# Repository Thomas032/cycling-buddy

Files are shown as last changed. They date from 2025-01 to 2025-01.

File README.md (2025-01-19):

## Cycling Buddy - Smart Cycling Computer

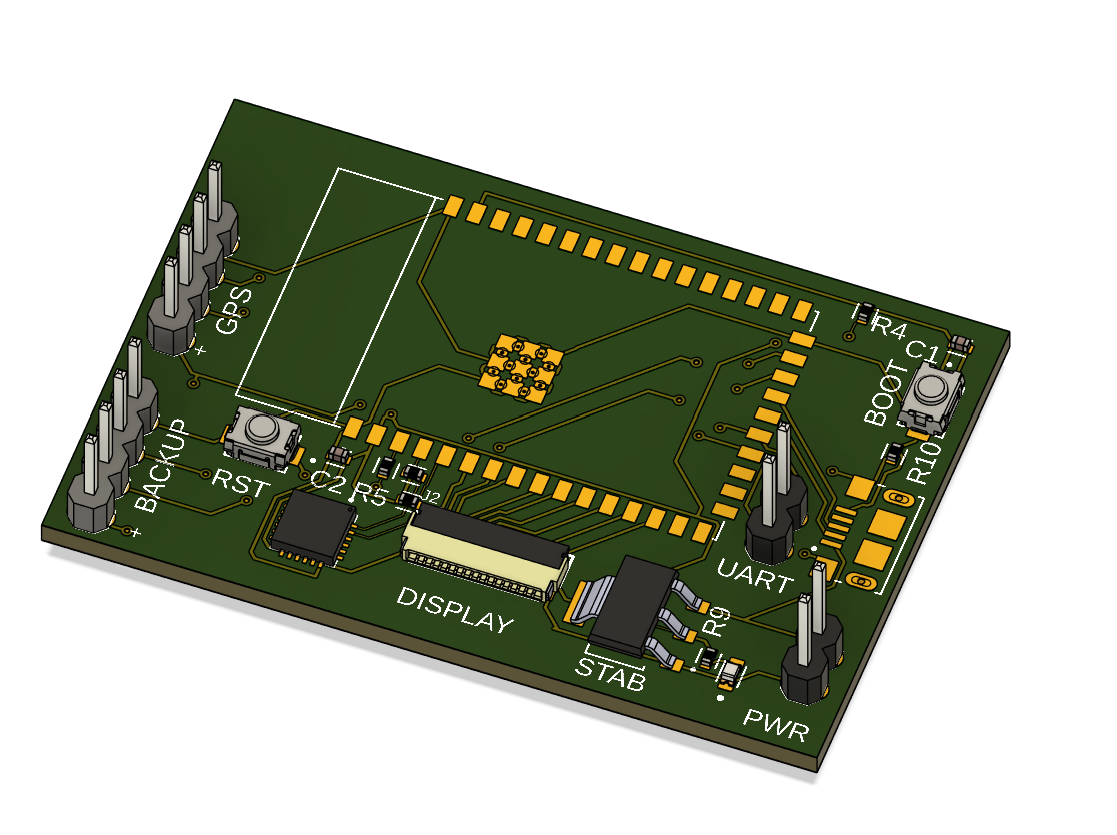
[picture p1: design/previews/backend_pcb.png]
Backend PCB
  
*The backend PCB design of Cycling Buddy.*

This is Cycling Buddy, a smart cycling computer I designed in 2023. The project aimed to fill a gap in the market while helping me improve my skills in PCB design, 3D modeling, and programming.

## Project Overview

Cycling Buddy consists of two main components:

### 1. **Compute Engine**
- **Location**: Housed within the bike’s steering shaft.
- **Features**:
  - **ESP32 Microcontroller**: The core of the compute engine, managing all system operations.
  - **Neo 6M GPS Module**: Enables real-time location tracking and navigation.
  - **MPU6050 Sensor**: Provides gyroscope and accelerometer data for precise movement and orientation tracking.
  - **Battery**: Powers the entire system.

### 2. **User Interface (UI)**
- **Features**:
  - **1.28" Round IPS Display**: Provides clear and vibrant visualization of data.
  - Buttons for user interaction and control.
- **Connection**: Wired connection to the compute engine (originally flex cable).

Due to an error in the original UI PCB design, the physical product had to be redesigned, and the UI PCB was ultimately not utilized in the final implementation.

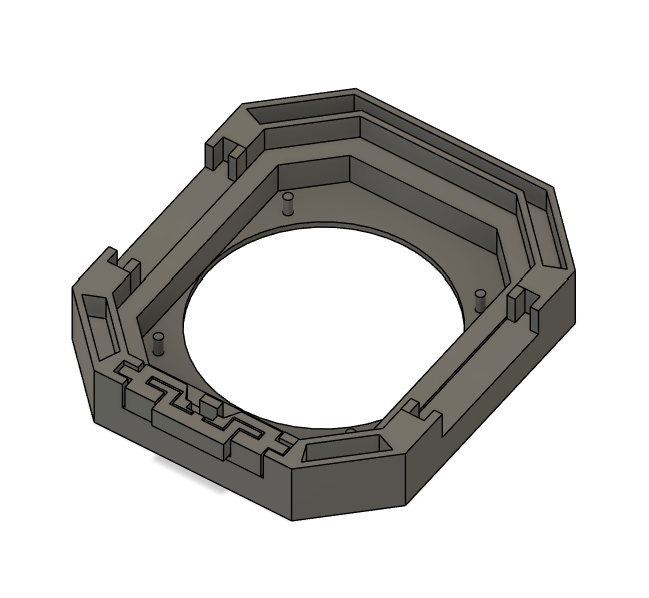
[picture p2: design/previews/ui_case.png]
UI Case
  
*Original UI case design for the Cycling Buddy.*

---

## Key Features
- **Modular Design**: Separate compute and UI components for flexibility and efficient upgrades.
- **Advanced Sensors**: Integration of GPS and MPU6050 for detailed tracking and analytics.
- **Custom Housing**: Designed to fit seamlessly within the bike's steering shaft for a sleek and practical solution.
- **Skill Development**: I got significantly better at:
  - PCB design
  - 3D modeling
  - Firmware and software development

---

## Technical Details
### Hardware
- **Microcontroller**: ESP32-S2-WROOM
- **Sensors**:
  - Neo 6M GPS Module
  - MPU6050 (Gyroscope and Accelerometer)
- **Power**: Rechargeable battery integrated into the compute engine
- **User Interface**:
  - 1.28" Round IPS Display
  - Buttons for navigation and control

### Software
- **Firmware**:
  - Developed for the ESP32 microcontroller.
  - Handles communication between sensors, UI, and external devices (intended for custom app communication).
- **Programming Languages**: C/C++ (for firmware)

### Mechanical Design
- **3D Modeled Housing**: Precision-designed to fit the bike’s steering shaft while protecting internal components.

---

## Challenges and Solutions
### Challenge: UI PCB Design Error
- **Issue**: An error in the UI board rendered it unusable.
- **Solution**: Redesigned the physical product to function without the UI PCB, ensuring the project remained operational.

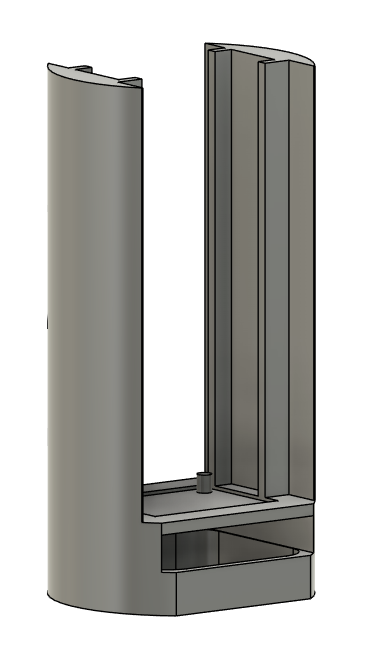
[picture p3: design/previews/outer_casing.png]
Outer Casing
  
*Outer casing design for the Cycling Buddy.*

### Challenge: Component Integration
- **Solution**: Iterative testing and debugging to ensure seamless communication between the compute engine and UI.

---

## Lessons Learned
This project significantly contributed to my growth in hardware and software development, particularly in:
- Iterative PCB design and error resolution.
- Advanced 3D modeling techniques for custom enclosures.
- Embedded programming for real-time systems.

I also learned how important it is to handle interference between components and data cables.

---

## Future Improvements
- **Move everything to 1 PCB**: Redesign the whole computer to utilize only one PCB and let the mobile app handle more complex tasks (positioning, real-time info, etc.).
- **Improved UI Design**: Finalize a revised UI PCB and incorporate additional features.
- **Enhanced Power Management**: Optimize battery life for longer usage.

---

## License
This project is licensed under the MIT License. See the `LICENSE` file for details.

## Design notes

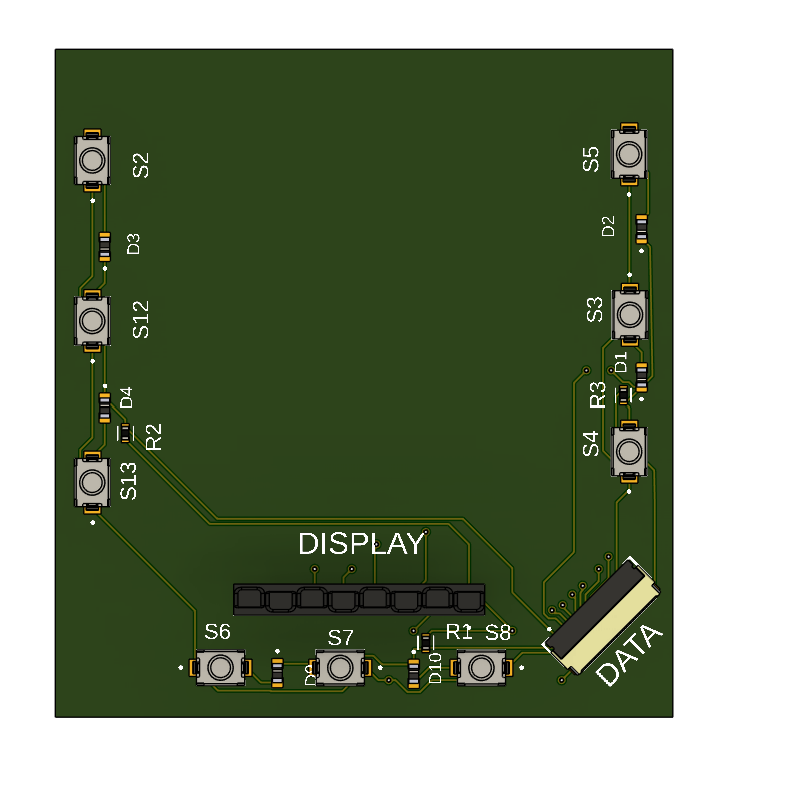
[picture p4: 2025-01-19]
design/previews/frontend_pcb.png

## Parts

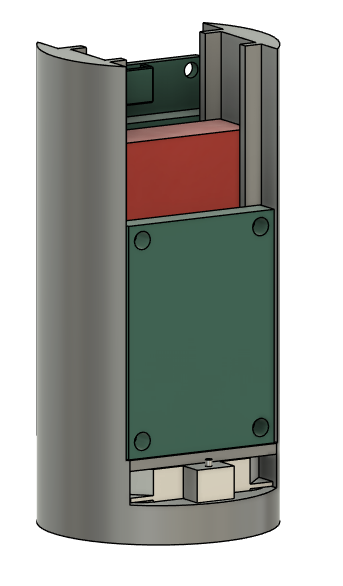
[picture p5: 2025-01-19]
design/previews/outer_casing_components.png

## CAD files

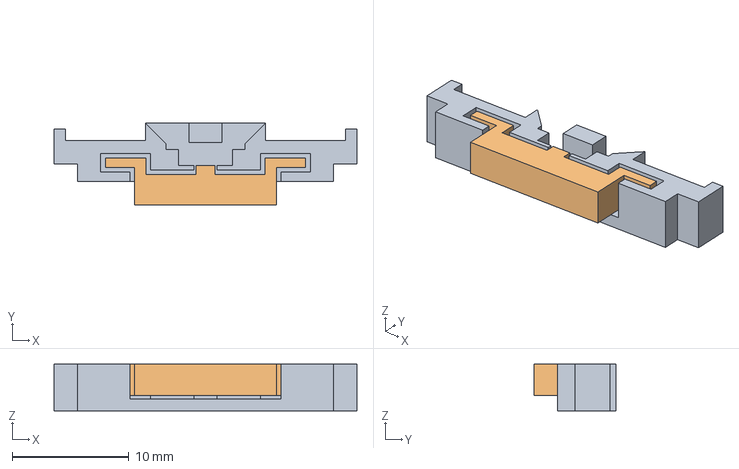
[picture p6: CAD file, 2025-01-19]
design/case/button_module.iges
26.0 x 7.00 x 4.00 mm

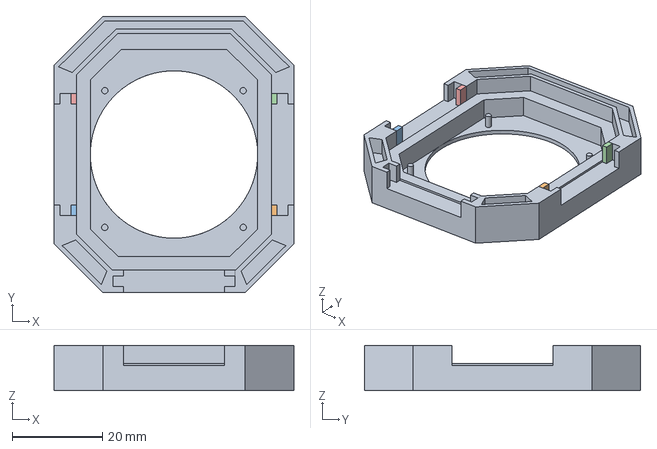
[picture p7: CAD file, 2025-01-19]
design/case/ui_cover.iges
53.0 x 61.0 x 10.0 mm

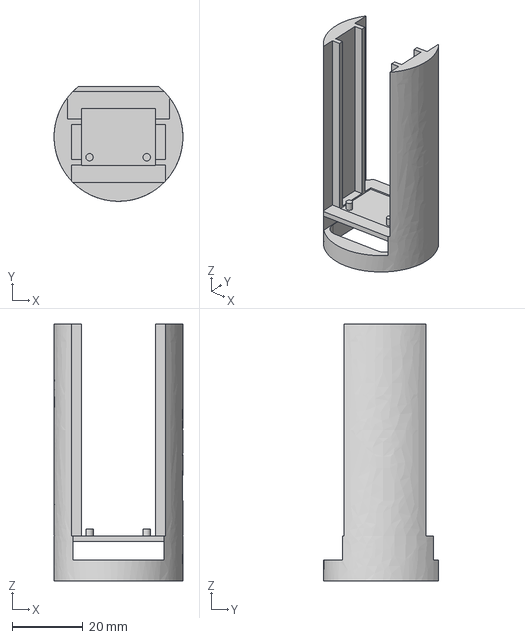
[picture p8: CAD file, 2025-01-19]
design/case/outer_casing.iges
36.5 x 32.5 x 72.8 mm

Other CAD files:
design/PCB/backend_pcb.f3z
design/PCB/ui_pcb.f3z

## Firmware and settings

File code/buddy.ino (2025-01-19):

#include <Arduino.h>
#include <TFT_eSPI.h>
#include <SPI.h>
#include <FreeRTOSConfig.h>
#include "freertos/FreeRTOS.h"
#include "freertos/task.h"
#include <math.h>
#include <String.h>
#include <Adafruit_MPU6050.h>
#include <Adafruit_Sensor.h>
#include <WiFi.h>
#include <AsyncTCP.h>
#include <ESPAsyncWebServer.h>
#include "code.h"
#include "lock_icon.h"
#include <ArduinoJson.h>
#include <SoftwareSerial.h>
#include <TinyGPSPlus.h>
#include <Preferences.h>
#include <math.h>

// #include "BluetoothSerial.h"

/* I/O */
#define BTN_R 34 // right button pin
#define BTN_L 13 // left button pin
#define BTN_C 25 // center button pin

/* GPS */
#define MY_TX 5
#define MY_RX 18
#define BAUD 9600

/* WIFI */
const char *ssid = "buddy";
const char *password = "password";

/* GENERAL */
#define WIDTH 240
#define HEIGHT 240
#define DEPTH 8    // color depth of panels
#define ROTATION 0 // display rotation
#define VERSION 1.0

/* DELAYS */
#define HELLO_DELAY 1000 / portTICK_PERIOD_MS // run time of greetings func
#define BTN_DELAY 150 / portTICK_PERIOD_MS    // delay when btn is pressed
#define TASK_DELAY 400 / portTICK_PERIOD_MS
#define UNDERLINE_SPEED 10 // define the speed of blinking line => x % UNDERLINE_SPEED == 0
#define BAR_HEIGHT 50      // height of the bottom and top bars
#define TRANSITION_DELAY_TICKS 10
#define BTN_TIMER_TRIGGER 30
#define SAVE_INTERVAL 1000
#define GPS_INTERVAL 2000
#define FALL_HOLD 3000
#define MPU_INTERVAL 300

/* SPRITE RELATED*/
#define PAGES 5   // number of tabs (speed, distance, ...)
#define BAR_X 70  // x pos of text in top/bottom bars
#define BAR_Y 20  // y pos -||-
#define MAIN_X 60 // x pos of text in the main screen
#define MAIN_Y 70 // y pos -||-
#define main_font 7
#define main_font_secondary 4
#define secondary_font 2

/* SETTINGS RELAED */
#define settings_cursor_width 10
#define settings_cursor_height 10

/* TRESHOLDS */
#define FALL_TRESHOLD 10.0
#define MOVEMENT_TRESHOLD 0.5

/* GPS transfer params */
#define LONG_PARAM "long"
#define LAT_PARAM "lat"
#define SPEED_PARAM "speed"
#define ALT_PARAM "alt"

/* OBJECTS */
AsyncWebServer server(80);
AsyncEventSource events("/data");

const size_t capacity = 10000;
DynamicJsonDocument doc(capacity);

Adafruit_MPU6050 mpu;
// BluetoothSerial SerialBT;
TFT_eSPI tft = TFT_eSPI();
TFT_eSprite top_bar = TFT_eSprite(&tft);
TFT_eSprite main_screen = TFT_eSprite(&tft);
TFT_eSprite bottom_bar = TFT_eSprite(&tft);
TFT_eSprite start = TFT_eSprite(&tft);
Preferences preferences;
EspSoftwareSerial::UART myPort;
TinyGPSPlus gps;

/* Timers */
hw_timer_t *time_counter = NULL;

/* GLOBAL vars */
int started = 0;
int btn_state;
int last_state = 0;
int color = TFT_RED;
int current_page_id = 0;
int last_page_id = 0;
int show = 1;
int in_settings = 0;
int in_sub_settings = 0;
int bluetooth_on = 0;
String ip_address = "";
String header_HTTP;

int setting_categories_n = 4;
int display_setting_categories_n = 2;
char *setting_categories[] = {"BACK", "CONNECT", "MESH", "INFO"};
char *display_setting_categories[] = {"BACK", "QR_CODE"};
int settings_start_x = 55;
int settings_start_y = 35;
int settings_font = 4;
int settings_pad = 10;
int settings_step = tft.fontHeight(settings_font);
int settings_cursor_x = settings_start_x - settings_pad - 5;
int settings_cursor_y = settings_start_y + (tft.fontHeight(settings_font) / 2) - 7;
int settings_cursor_step = settings_step + settings_pad;
int settings_cursor_index = 0;
int finished = 0;
int interrupted = 0;
int locked = 0;
int gps_recieved = 0;

unsigned long lastExecutedMillis = 0;    // vairable to save the last executed time
unsigned long lastExecutedMillisGPS = 0; // vairable to save the last executed time
int data_index = 0;

int center_btn_timer = 0;
int center_btn_panic_timer = 0;
int stop_timer = 3;

int time_passed = 0; // time that passed from the start
int minutes = 0;     // elapsed minutes
int hours = 0;       // elapsed hours from the start
float seconds = 0;   // elapsed seconds from the start
float displayed_seconds = 0.00;
int transition_ticks = 0;

String speed_measure = "Km/h";
int max_speed = 0; // maximum recorded speed per ride

float angle_lr = 0; // angle when movinf left and right
float angle_fr = 0; // angle when rotating to your self and from your self (Slope)
int fall_detected = 0;
float fell_time = 0;
int angle_index = 0;
float last_read_angle = 0.0;
float angle_lr_filter[4] = {0, 0, 0, 0};
float angle_fr_filter[4] = {0, 0, 0, 0};
float locked_accel_x = -1.0;
float locked_accel_y = -1.0;
float locked_accel_z = -1.0;

/* TIMER VARS -> WiFi*/
unsigned long lastTime = 0;
unsigned long timerDelay = 10000;

float last_lat = 0;
float last_long = 0;
float current_lat = 0;
float current_long = 0;
unsigned age = 0;
double total_dist = 0.00;
float altitude = 0;
float speed = 0.00;
int bike_moved = 0;

/* PROTOTYPES */
void IRAM_ATTR Timer_ISR();

void setup()
{
  Serial.begin(115200);

  /* PREFERECES */
  preferences.begin("buddy", false);

  /* GPS */
  myPort.begin(9600, SWSERIAL_8N1, MY_RX, MY_TX);
  if (!myPort)
  { // If the object did not initialize, then its configuration is invalid
    Serial.println("Invalid EspSoftwareSerial pin configuration, check config");
    while (1)
    { // Don't continue with invalid configuration
      delay(100);
    }
  }
  Serial.println("GPS setup successfull");

  /* WiFi */
  Serial.print("Setting AP (Access Point)…");
  WiFi.enableAP(true);
  WiFi.softAP(ssid, password, 1, 1, 1);

  IPAddress IP = WiFi.softAPIP();
  Serial.print("AP IP address: ");
  ip_address = String(IP);
  Serial.println(IP);

  server.on("/data", HTTP_GET, [](AsyncWebServerRequest *request)
            {
    if(!finished){
      save_data();
      String json;
      serializeJson(doc, json);
      request->send(200, "application/json", json);
      json = String();
    }
    else{
      request->send(200, "text/plain", "OVER");
    } });

  server.on("/lock-device", HTTP_GET, [](AsyncWebServerRequest *request)
            {
    if(!finished){
      top_bar.fillSprite(TFT_BLACK);
      main_screen.fillSprite(TFT_BLACK);
      bottom_bar.fillSprite(TFT_BLACK);
      locked = 1;
      request->send(200, "text/plain", "LOCKED");
    } });

  server.on("/unlock-device", HTTP_GET, [](AsyncWebServerRequest *request)
            {
    if(!finished){
      top_bar.fillSprite(TFT_BLACK);
      main_screen.fillSprite(TFT_BLACK);
      bottom_bar.fillSprite(TFT_BLACK);
      locked = 0;
      bike_moved = 0;
      request->send(200, "text/plain", "UNLOCKED");
    } });

  server.on("/data_transferred", HTTP_GET, [](AsyncWebServerRequest *request)
            {
    doc.clear();
    data_index = 0;
    request->send(200, "text/plain", "OK"); });

  server.on("/GPS", HTTP_GET, [](AsyncWebServerRequest *request)
            {
    if(request->hasParam(LONG_PARAM)){
      gps_recieved = 1;
      current_long = (float)request->getParam(LONG_PARAM)->value();
    }
    if(request->hasParam(LAT_PARAM)){
      current_lat = (float)request->getParam(LAT_PARAM)->value();
    }
    if(request->hasParam(ALT_PARAM)){
      altitude = (float)request->getParam(altitude)->value();
    }
    if(request->hasParam(SPEED_PARAM)){
      speed = (float)request->getParam(altitude)->value();
    } });

  server.begin();

  /*MPU-6050*/
  Wire.setPins(4, 16);
  mpu.begin();
  mpu.setAccelerometerRange(MPU6050_RANGE_16_G);
  mpu.setGyroRange(MPU6050_RANGE_250_DEG);
  mpu.setFilterBandwidth(MPU6050_BAND_21_HZ);

  /* TFT_ESPI */
  tft.init();
  tft.setRotation(ROTATION);

  /* I/O */
  pinMode(BTN_L, INPUT);
  pinMode(BTN_C, INPUT);
  pinMode(BTN_R, INPUT);

  /* TIMERS */
  time_counter = timerBegin(0, 80, true);
  timerAttachInterrupt(time_counter, &Timer_ISR, true);
  timerAlarmWrite(time_counter, 1000, true);

  startup_code();
}

void loop()
{
  if (locked)
  {
    lock_screen();
  }
  else
  {
    bar_init();
    handle_page_display();
    handle_page_movement();
    check_for_halt();
    wifi_fnc();
    check_for_fall();
  }
  unsigned long currentMillis = millis();
  if (currentMillis - lastExecutedMillis >= SAVE_INTERVAL)
  {
    lastExecutedMillis = currentMillis; // save the last executed time
    if (interrupted)
    {
      save_data();
    }
    get_GPS();
    handle_gps();
  }
}

void save_data()
{
  // JsonObject data = doc.createNestedObject(String(data_index));
  doc["speed"] = get_speed();
  doc["distance"] = get_distance();
  doc["time_elapsed"] = (double)time_passed / 1000;
  doc["fall_detected"] = fall_detected;
  doc["lat"] = current_lat;
  doc["long"] = current_long;
  doc["alt"] = altitude;
  doc["alarm"] = bike_moved;
  data_index++;
}

/* SETUP funcs */
void IRAM_ATTR Timer_ISR()
{
  if (!locked)
  {
    time_passed += 1;
  }
}

void greeting()
{
  tft.drawString("Cycling Buddy v" + String(VERSION), 60, HEIGHT / 2, 2);
  vTaskDelay(HELLO_DELAY);
}

void startup_code()
{
  /* TFT_eSPI */
  top_bar.setColorDepth(DEPTH);
  top_bar.createSprite(WIDTH, BAR_HEIGHT);
  top_bar.setTextColor(TFT_WHITE, TFT_BLACK);

  main_screen.setColorDepth(DEPTH);
  main_screen.createSprite(WIDTH, (HEIGHT - (2 * BAR_HEIGHT)));
  main_screen.setTextColor(TFT_WHITE, TFT_BLACK);

  bottom_bar.setColorDepth(DEPTH);
  bottom_bar.createSprite(WIDTH, BAR_HEIGHT);
  bottom_bar.setTextColor(TFT_WHITE, TFT_BLACK);

  start.setColorDepth(DEPTH);
  start.createSprite(WIDTH, HEIGHT);

  tft.fillScreen(TFT_BLACK);
  greeting();
  tft.fillScreen(TFT_BLACK);
  start_screen();

  while (!started)
  {
    if (!in_settings)
    {
      start_screen();
    }
    else
    {
      settings_screen();
    }
  }
  timerAlarmEnable(time_counter); // start the timer when user clicks START
}

void start_screen()
{
  int pad = 8;

  int start_x = 80;
  int start_y = 150;
  String start_txt = "START";

  int start_arrow_x = start_x + (tft.textWidth(start_txt, 4) / 2);
  int start_arrow_y = start_y + pad + tft.fontHeight(4);

  int settings_x = 40;
  int settings_y = 80;
  String settings_txt = "SETTINGS";

  int settings_arrow_x = settings_x + tft.textWidth(settings_txt, 4) + 15;
  int settings_arrow_y = settings_y + (tft.fontHeight(4) / 2) - 4;

  // start.pushSprite(0, 0);

  tft.drawString(start_txt, start_x, start_y, 4);
  tft.drawString(settings_txt, settings_x, settings_y, 4);

  /* arrow pointing downward */
  tft.drawFastVLine(start_arrow_x, start_arrow_y, 20, TFT_WHITE);
  tft.drawLine(start_arrow_x, start_arrow_y + 20, start_arrow_x - 10, start_arrow_y + 10, TFT_WHITE);
  tft.drawLine(start_arrow_x, start_arrow_y + 20, start_arrow_x + 10, start_arrow_y + 10, TFT_WHITE);

  /* arrow poiting right */
  tft.drawFastHLine(settings_arrow_x, settings_arrow_y, 20, TFT_WHITE);
  tft.drawLine(settings_arrow_x + 20, settings_arrow_y, (settings_arrow_x + 20) - 10, settings_arrow_y - 10, TFT_WHITE);
  tft.drawLine(settings_arrow_x + 20, settings_arrow_y, (settings_arrow_x + 20) - 10, settings_arrow_y + 10, TFT_WHITE);

  if (digitalRead(BTN_C))
  {
    tft.fillScreen(TFT_BLACK);
    vTaskDelay(BTN_DELAY);
    if (WiFi.softAPgetStationNum() > 0)
    {
      started = 1;
    }
    else
    {
      String prompt = "No device connected!";
      int x = (WIDTH - tft.textWidth(prompt, main_font_secondary)) / 2;
      int y = (HEIGHT - tft.fontHeight(main_font_secondary)) / 2;
      tft.drawString(prompt, x, y, main_font_secondary);
      vTaskDelay(BTN_DELAY * 4);
      tft.fillScreen(TFT_BLACK);
    }
  }

  if (digitalRead(BTN_R))
  {
    // start.fillSprite(TFT_BLACK);
    tft.fillScreen(TFT_BLACK);
    vTaskDelay(BTN_DELAY);
    in_settings = 1;
  }
}

void settings_screen()
{
  menu(setting_categories_n, setting_categories, &settings_cursor_index);
}

void bar_init()
{
  top_bar.pushSprite(0, 0);
  main_screen.pushSprite(0, BAR_HEIGHT);
  bottom_bar.pushSprite(0, HEIGHT - BAR_HEIGHT);

  top_bar.fillSprite(TFT_BLACK);
  top_bar.drawFastHLine(0, BAR_HEIGHT - 1, WIDTH, TFT_WHITE);

  main_screen.fillScreen(TFT_BLACK);

  bottom_bar.fillSprite(TFT_BLACK);
  bottom_bar.drawFastHLine(0, 0, WIDTH, TFT_WHITE);
}

/* MENU functions */

void menu(int n_items, char **setting_categories, int *index_var)
{
  // start.pushSprite(0, 0);
  handle_menu_array(setting_categories, n_items);
  handle_menu_cursor(index_var, &n_items);
  *index_var = handle_menu_buttons(*index_var);
}

void handle_menu_cursor(int *cursor_index, const int *N)
{
  if (*cursor_index < 0 || *cursor_index > (*N - 1))
  {
    *cursor_index = 0;
  }
  tft.fillSmoothRoundRect(settings_cursor_x, settings_cursor_y + (*cursor_index * settings_cursor_step), settings_cursor_width, settings_cursor_height, 2, TFT_WHITE);
}

void handle_menu_array(char **items, int N)
{
  for (int i = 0; i < N; i++)
  {
    tft.drawString(*items, settings_start_x, settings_start_y + (i * (settings_step + settings_pad)), settings_font);
    items++;
  }
}

int handle_menu_buttons(int cursor_index)
{
  if (digitalRead(BTN_C))
  {
    handle_menu_functions(&cursor_index, &in_settings);
    vTaskDelay(BTN_DELAY);
    // start.fillSprite(TFT_BLACK);
  }
  if (digitalRead(BTN_L))
  {
    cursor_index--;
    vTaskDelay(BTN_DELAY);
    tft.fillSmoothRoundRect(0, 0, settings_start_x, HEIGHT, 1, TFT_BLACK); // overdraw the cursor area
  }
  if (digitalRead(BTN_R))
  {
    cursor_index++;
    vTaskDelay(BTN_DELAY);
    tft.fillSmoothRoundRect(0, 0, settings_start_x, HEIGHT, 1, TFT_BLACK); // overdraw the cursor area
  }
  return cursor_index;
}

void handle_menu_functions(int *cursor_index, int *back_int)
{
  switch (*cursor_index)
  {
  case 0:
    tft.fillScreen(TFT_BLACK);
    *back_int = 0;
    break;
  case 1:
    in_sub_settings = 1;
    tft.fillScreen(TFT_BLACK);
    vTaskDelay(BTN_DELAY);
    while (in_sub_settings)
    {
      connect_page();
    }
    break;
  case 3:
    in_sub_settings = 1;
    tft.fillScreen(TFT_BLACK);
    vTaskDelay(BTN_DELAY);
    while (in_sub_settings)
    {
      info_page();
    }
    break;
  }
}

void info_page()
{
  // start.pushSprite(0,0);
  // tft.fillScreen(TFT_BLACK);
  String header = "Cycling buddy";
  int start_x = (WIDTH - tft.textWidth(header)) / 2;
  int start_y = 30;
  int text_height = tft.fontHeight(secondary_font);
  int pad = 10;

  tft.drawString("Cycling buddy", start_x, start_y, secondary_font);
  tft.drawFastHLine(0, start_y + text_height + pad, WIDTH, TFT_WHITE);

  int text_start_x = 30;
  int text_start_y = start_y + text_height + pad * 2;

  tft.drawString("Version: " + String(VERSION), text_start_x, text_start_y, secondary_font);
  tft.drawString("IP address: " + get_ip(WiFi.softAPIP()), text_start_x, text_start_y + text_height, secondary_font);
  tft.drawString("MAC address: " + String(WiFi.macAddress()), text_start_x, text_start_y + text_height * 2, secondary_font);
  tft.drawString("Connected devices " + String(WiFi.softAPgetStationNum()), text_start_x, text_start_y + text_height * 3, secondary_font);

  // tft.drawString("Connection: " + connection_status(), text_start_x, text_start_y + text_height * 2, secondary_font);

  if (digitalRead(BTN_C) | digitalRead(BTN_L) | digitalRead(BTN_R))
  {
    in_sub_settings = 0;
    vTaskDelay(BTN_DELAY);
    tft.fillScreen(TFT_BLACK);
  }
}

void connect_page()
{
  tft.pushImage(60, 60, 125, 125, qr_code);
  if (digitalRead(BTN_C) | digitalRead(BTN_L) | digitalRead(BTN_R))
  {
    in_sub_settings = 0;
    vTaskDelay(BTN_DELAY);
    tft.fillScreen(TFT_BLACK);
  }
}

String get_ip(IPAddress ip)
{
  String s = "";
  for (int i = 0; i < 4; i++)
    s += i ? "." + String(ip[i]) : String(ip[i]);
  return s;
}

/*LOOP (PAGE) FUNCTIONS */

void lock_screen()
{
  sensors_event_t a, g, temp;
  mpu.getEvent(&a, &g, &temp);

  float accel_x = a.acceleration.x;
  float accel_y = a.acceleration.y;
  float accel_z = a.acceleration.z;

  if (round(locked_accel_x) == -1 && round(locked_accel_y) == -1 && round(locked_accel_y) == -1)
  {
    // locked position not set yet
    locked_accel_x = accel_x;
    locked_accel_y = accel_y;
    locked_accel_z = accel_z;
  }
  else
  {
    // check for movement
    float delta_x = abs(accel_x - locked_accel_x);
    float delta_y = abs(accel_y - locked_accel_y);
    float delta_z = abs(accel_z - locked_accel_z);

    if (delta_x > MOVEMENT_TRESHOLD || delta_y > MOVEMENT_TRESHOLD || delta_z > MOVEMENT_TRESHOLD)
    {
      // bike moved -> inform the user
      bike_moved = 1;
    }
  }
  // main_screen.pushImage(25,0, 95, 110, lock);
}

void get_GPS()
{
  /*
  myPort.listen();
  if(myPort.available() > 0){
    int teststr = myPort.read();
     if (gps.encode((char) teststr))
      displayInfo();
  }
  */
  const char *gpsStream =
      "$GPRMC,154533.00,A,5028.24345,N,01324.32805,E,0.039,,080523,,,A*70\r\n"
      "$GPVTG,,T,,M,0.039,N,0.073,K,A*2D\r\n"
      "$GPGGA,154533.00,5028.24345,N,01324.32805,E,1,09,0.96,358.7,M,44.7,M,,*52\r\n"
      "$GPGSA,A,3,03,08,32,10,27,02,14,21,01,,,,1.81,0.96,1.54*0E\r\n"
      "$GPGSV,3,1,10,01,42,286,25,02,26,099,32,03,11,228,30,08,60,188,39*7C\r\n"
      "$GPGSV,3,2,10,10,36,056,46,14,20,309,25,21,71,296,35,22,32,131,42*7C\r\n"
      "$GPGSV,3,3,10,27,31,158,41,32,42,101,39*7B\r\n"
      "$GPGLL,5028.24345,N,01324.32805,E,154533.00,A,A*6F\r\n"
      "$GPRMC,154534.00,A,5028.24346,N,01324.32811,E,0.059,,080523,,,A*77\r\n"
      "$GPVTG,,T,,M,0.059,N,0.109,K,A*27\r\n"
      "$GPGGA,154534.00,5028.24346,N,01324.32811,E,1,09,0.96,358.3,M,44.7,M,,*57\r\n"
      "$GPGSA,A,3,03,08,32,10,27,02,14,21,01,,,,1.81,0.96,1.54*0E\r\n"
      "$GPGSV,3,1,10,01,42,286,25,02,26,099,34,03,11,228,30,08,60,188,40*74\r\n"
      "$GPGSV,3,2,10,10,36,056,47,14,20,309,26,21,71,296,35,22,32,131,43*7F\r\n"
      "$GPGSV,3,3,10,27,31,158,42,32,42,101,40*76\r\n"
      "$GPGLL,5028.24346,N,01324.32811,E,154534.00,A,A*6E\r\n"
      "$GPRMC,154535.00,A,5028.24347,N,01324.32817,E,0.064,,080523,,,A*7F\r\n";

  while (*gpsStream)
  {
    gps.encode(*gpsStream++);
  }
}

void handle_gps()
{
  current_lat = gps.location.lat();
  current_long = gps.location.lng();
  altitude = gps.altitude.meters();
  if (last_lat == 0 && last_long == 0)
  {
    last_lat = current_lat;
    last_long = current_long;
    Serial.println("NEW LOCATION!");
  }
  // read the distance between 2 points (last and new)
  double dist = distance(last_lat, last_long, current_lat, current_long);

  if (dist > 5)
  {
    // add current dist to total dist
    total_dist += dist;
  }

  last_lat = current_lat;
  last_long = current_long;
}

void displayInfo()
{
  Serial.print(F("Location: "));
  if (gps.location.isValid())
  {
    Serial.print(gps.location.lat(), 6);
    Serial.print(F(","));
    Serial.print(gps.location.lng(), 6);
  }
  else
  {
    Serial.print(F("INVALID"));
  }

  Serial.print(F("  Date/Time: "));
  if (gps.date.isValid())
  {
    Serial.print(gps.date.month());
    Serial.print(F("/"));
    Serial.print(gps.date.day());
    Serial.print(F("/"));
    Serial.print(gps.date.year());
  }
  else
  {
    Serial.print(F("INVALID"));
  }

  Serial.print(F(" "));
  if (gps.time.isValid())
  {
    if (gps.time.hour() < 10)
      Serial.print(F("0"));
    Serial.print(gps.time.hour() + 2);
    Serial.print(F(":"));
    if (gps.time.minute() < 10)
      Serial.print(F("0"));
    Serial.print(gps.time.minute());
    Serial.print(F(":"));
    if (gps.time.second() < 10)
      Serial.print(F("0"));
    Serial.print(gps.time.second());
    Serial.print(F("."));
    if (gps.time.centisecond() < 10)
      Serial.print(F("0"));
    Serial.print(gps.time.centisecond());
  }
  else
  {
    Serial.print(F("INVALID"));
  }

  Serial.println();
}

void wifi_fnc()
{
  int n = WiFi.softAPgetStationNum();
  if (n == 0)
  {
    interrupted = 1;
  }
  else
  {
    interrupted = 0;
  }
}

void check_for_halt()
{
  if (digitalRead(BTN_C))
  {
    if (center_btn_timer < BTN_TIMER_TRIGGER)
    {
      center_btn_timer++;
    }
    else
    {
      // call halt function
      top_bar.fillSprite(TFT_BLACK);
      main_screen.fillSprite(TFT_BLACK);
      bottom_bar.fillSprite(TFT_BLACK);
      display_stop("STOP");
      if (center_btn_panic_timer < BTN_TIMER_TRIGGER)
      {
        center_btn_panic_timer++;
      }
      else
      {
        // end functions
        finished = 1;
        esp_deep_sleep_start();
      }
    }
  }
  else
  {
    center_btn_timer = 0;
    center_btn_panic_timer = 0;
  }
}

void check_for_fall()
{
  // FALL DETECTION
  sensors_event_t a, g, temp;
  mpu.getEvent(&a, &g, &temp);
  float accel_x = a.acceleration.x;
  float accel_y = a.acceleration.y;
  float accel_z = a.acceleration.z;

  float accel_total = sqrt(pow(accel_x, 2) + pow(accel_y, 2) + pow(accel_z, 2));

  if (accel_total > FALL_TRESHOLD)
  {
    fell_time = millis();
    fall_detected = 1;
  }
  else if (fell_time - millis() >= FALL_HOLD)
  {
    fell_time = 0;
    fall_detected = 0;
  }
}

void handle_page_movement()
{
  if (current_page_id != last_page_id)
  {
    transition_ticks = 0;
    bar_init();
    last_page_id = current_page_id;
  }

  if (digitalRead(BTN_R))
  {
    if (current_page_id > PAGES)
      current_page_id = 0;
    else
      current_page_id++;
    vTaskDelay(BTN_DELAY);
  }
  if (digitalRead(BTN_L))
  {
    if (current_page_id == 0)
      current_page_id = PAGES - 1;
    else
      current_page_id--;
    vTaskDelay(BTN_DELAY);
  }
}

void handle_page_display()
{
  switch (current_page_id)
  {
  case 0:
    page_0_fnc();
    break;
  case 1:
    page_1_fnc();
    break;
  case 2:
    page_2_fnc();
    break;
  case 3:
    page_3_func();
    break;
  case 4:
    page_4_fnc();
    break;
  case 5:
    if (interrupted)
    {
      page_5_func();
    }
    else
    {
      current_page_id++;
    }
    break;
  default:
    page_0_fnc();
    break;
  }
}
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
